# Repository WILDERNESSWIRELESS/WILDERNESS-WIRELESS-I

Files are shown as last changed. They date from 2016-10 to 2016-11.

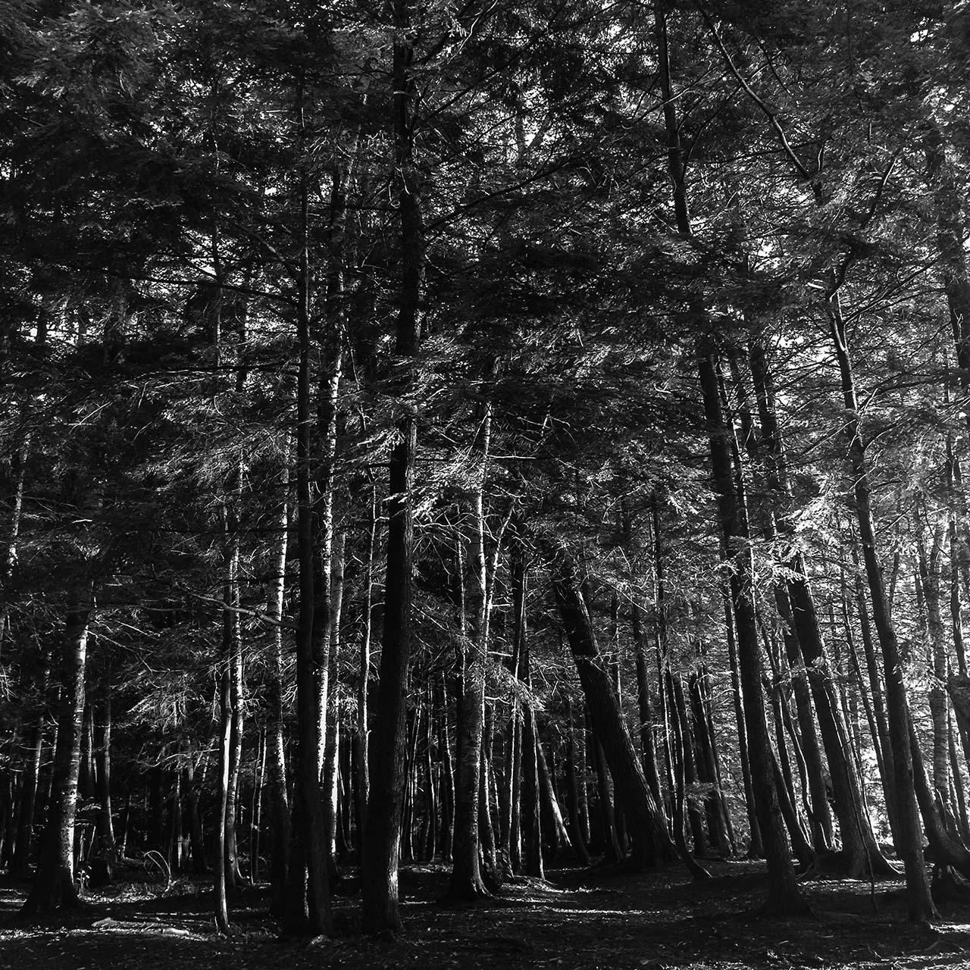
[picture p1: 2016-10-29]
docs/www.jpg

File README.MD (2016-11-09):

# Wilderness Wireless Map

## INTRODUCTION

### About

The following are instructions for making your very own Solar-Powered Wilderness Wireless WiFi Access Point and Web Server. When you are finished, there will be an access point (AP) with a name (SSID) of your own choosing. When you or someone else connects to this AP with a phone or computer, a captive portal page will open, displaying a web page of your own design, not unlike the captive portal pages of some paid public wifi networks. This personal area network (PAN) is not connected to the internet and does not provide a route to any place on the internet. This AP is in essence its own internet. After connecting, all http requests are resolved to the internal address. The information contained here has been pulled from many difference sources and integrates the work of many others without whose work this project would not be possible. Please see the references.md file for acknowedgements and links to sources.

### Materials and Tools

A comprehensive list of materials is provided as an Adafruit wishlist that can be accessed [here]() You may try to source materials from other places, but there is no guarantee the project will work as expected. This project involves soldering, so a basic set of electronics tools is required. Here's a general list of useful things:
 * Soldering iron
 * Soldering Iron Tip Cleaner
 * Solder
 * Wire Strippers
 * Wire Cutters
 * Needle Nose Pliers
 * Multimeter
 * Lighter or Heat Gun

### Disclaimer

This information is provided free and without warranty. I offer no guarantee that this project will work as stated. The author or any of the included sources are not responsible for any wrongdoing, damage, transgression of rules, laws or regulations. Use at your own risk.

### License

**CC** Creative Commons Attribution, Non-Commercial Share-Alike

## PHASE 1

### Prepare and Solder Hardware

- **Solder Capacitor on Charger**
  * You can find instructions from Adafruit [here](https://learn.adafruit.com/usb-dc-and-solar-lipoly-charger/solar-charger-preparation)

- **Solder JST connector**
  * The Adafruit charger comes with a JST connector with bare wire ends. It is difficult to  plug these tiny wires into a breadboard, so cut a jumper wire in half, solder each end to a bare wire. Use heat-shring tubing to insulate wires. Hold onto this DIY cable for now...

- **Solder Headers on the Feather**
  * The Adafruit Feather Huzzah ESP8266 comes with male header pins. You must cut the headers to the correct length and solder them to the board. You can find instructions from Adafruit [here](https://learn.adafruit.com/adafruit-feather-huzzah-esp8266/using-arduino-ide?view=all#assembly)

- **Charge Battery**
  * Plug the LiPoly battery's JST connector into the BATT port on the charger. You can charge the battery by connecting the charger to your laptop or a wall adapter/charger with a mini USB cable.

### Install Software Tools and Their Dependencies

! _WIN users might have an easier time using NodeMCU Flasher instead of setting up python, etc. It can be found [here](https://github.com/nodemcu/nodemcu-flasher)_

  - **Prepare esptool.py**
    * The Adafruit Feather already has NodeMCU firmware installed, but we need to use a custom version for our web server to work properly. The firmware is flashed to the Feather using a Python tool called esptool.py. You must first determine if you have Python installed.
      * **OSX:** Open Terminal (if you don't know where it is, search in spotlight). Type ``` python --version``` in the terminal. You should see something like ```Python 2.7.10``` returned. If not, skip down to Python installation.
      * **WIN:** Search for run or run.exe. Type CMD in the run dialog box. The command line terminal should open. Type ``` python --version``` in the terminal. You should see something like ```Python 2.7.10``` returned. If not, skip down to Python installation.
    * Install Python if you don't have it. Get it [here](https://www.python.org/downloads/)
    * esptool.py is a python program that will help you flash firmware to the Feather. You can find instructions [here](https://github.com/espressif/esptool)
  * **Install VCPdrivers for Feather:** The Feather uses a Silicon Labs CP2104 USB-Serial converter onboard with 921600 max baudrate for uploading. You must install drivers for this chip before connecting it to your computer and flashing the firmware. Download and install the Virtual Com Port drivers for you operating system [here](https://www.silabs.com/products/mcu/Pages/USBtoUARTBridgeVCPDrivers.aspx)
  * **Connect Feather to your computer with a micro USB cable.**
  * **Locate firmware.** The firmware for the Feather is located in the _firmware_ folder in this repository. It is easiest to navigate to that folder using your command line terminal. The firmware file is: ```NodeMCU-FW-CaptiveIntraweb.bin```
  * **Flash Firmware:** With Python, esptool.py and VCP drivers now installed, flash the firmware using this command in your terminal:
  ```
  esptool.py --port /dev/tty.SLAB_USBtoUART
    write_flash -fm dio
    -fs 32m 0x00000
    NodeMCU-FW-CaptiveIntraweb.bin
  ```
  The device you are flashing is usually ```/dev/tty.SLAB_USBtoUART``` on OSX or something like ```COM3``` on Windows. Replace ```/dev/tty.SLAB_USBtoUART``` with the correct port if different.

  ## PHASE 2

  ### Communicating With Feather

  Communication with the Feather NodeMCU firmware can be done via a Serial Terminal Application like CoolTerm (WIN/OSX) or Screen (OSX/NIX). A useful application is ESPLorer which provides a FTP-like interface for manipulating files on the Feather. Since we are going to use the Feather as a Web Server, this seems like the best tool for the job. ESPlorer application is a cross-platform Java application. You can get it from the Download it from the _tools_ folder in this repository or alternatively download it [here](http://esp8266.ru/esplorer/). Since ESPLorer is a java application, you need to have a recent version of the Java Runtime Environment (JRE) installed on your machine to use it. Try to open the _**ESPLorer.jar**_ file. If it doesn't open, you probably don't have java installed. The JRE is free and can be downloaded [here](http://www.oracle.com/technetwork/java/javase/downloads/jre8-downloads-2133155.html).

  ### Edit Server Files

  This is your own access point and webserver. You have control over the name of the accesspoint and the content of the web page. In keeping with the idea of wilderness wireless, think about what you might name your AP. Does a wilderness wireless network use a particular language? Does it have to be intelligible? Think about stumbling across a wireless network in the wilderness where there are no others around. What kind of content might you find in this network? Is it text, an image, perhaps just a color? 

  ### Upload Server Files

  ## PHASE 3

  ### Breadboard circuit

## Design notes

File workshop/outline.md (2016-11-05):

hack tutorial
orientation: the spirit of the project
https://en.wikipedia.org/wiki/Mycorrhiza
beacons
Throwies
http://www.graffitiresearchlab.com/blog/projects/led-throwies/

aram bartholl dead drops
https://deaddrops.com/

Wilderness-unplugging

software Tools
  vcp drivers
  esptool
  firmware
  esplorer

soldering
  headers
  cap
  jst/

circuit
    fritzing

flash modified node mcu firmware

play with node mcu/

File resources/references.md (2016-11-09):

# References

## Rad Networks WiFi

~~SSID: RadNetz~~

~~PWD: R@@0n3wrks~~

## github

#### The Wilderness Wireless Repository is here:

https://giantmolecules.github.io/WILDERNESS-WIRELESS/

## Arduino/ATTINY85 Battery Watchdog

#### Wake an Arduino from sleep with a watchdog timer

http://donalmorrissey.blogspot.com/2010/04/sleeping-arduino-part-5-wake-up-via.html

http://arduino.stackexchange.com/questions/19501/watchdog-approach

#### ATTINY Pinouts

http://orig06.deviantart.net/82c9/f/2013/038/3/7/attiny_web_by_pighixxx-d5u4aur.png

#### Adafruit Feather HUZZAH ESP8266

https://learn.adafruit.com/adafruit-feather-huzzah-esp8266

#### Adafruit USB, DC & Solar Lipoly Charger

https://learn.adafruit.com/usb-dc-and-solar-lipoly-charger/using-the-charger

#### Atmel sleep reference

http://www.atmel.com/webdoc/AVRLibcReferenceManual/group__avr__sleep.html

#### Measuring battery voltage with arduino

http://provideyourown.com/2012/secret-arduino-voltmeter-measure-battery-voltage/

http://digistump.com/wiki/digispark/quickref

#### Tiny AVR Programmer

https://github.com/sparkfun/Tiny-AVR-Programmer/tree/V_1.3

https://www.sparkfun.com/products/11801

## Adafruit Feather HUZZAH ESP8266

#### NodeMCU Documentation

https://nodemcu.readthedocs.io/en/master/

## ESPlorer

#### ESPlorer Homepage

http://esp8266.ru/esplorer/

#### Java Runtime Environment

http://www.oracle.com/technetwork/java/javase/downloads/jre8-downloads-2133155.html

## General

#### UTF-8 Charset

http://www.w3schools.com/charsets/ref_html_utf8.asp

## Inspiration

#### LED Throwies

http://www.graffitiresearchlab.com/blog/projects/led-throwies/

#### ESP8266 WiFi Throwies

http://hackaday.com/2015/05/03/esp8266-wifi-throwies/

## Wilderness Networks

#### Forestry Communication Tools

http://www.fao.org/forestry/communication-toolkit/en/

#### Internet of Fungus

http://www.bbc.com/earth/story/20141111-plants-have-a-hidden-internet

## Wood Wide web

http://www.newyorker.com/tech/elements/the-secrets-of-the-wood-wide-web

https://en.wikipedia.org/wiki/Mycorrhizal_network

https://rayalaseema360.wordpress.com/2016/01/31/trees-have-their-own-internet-wood-wide-web/

## LED Throwies

http://www.graffitiresearchlab.com/blog/projects/led-throwies/

## Aram Bartholl dead drops

https://deaddrops.com/

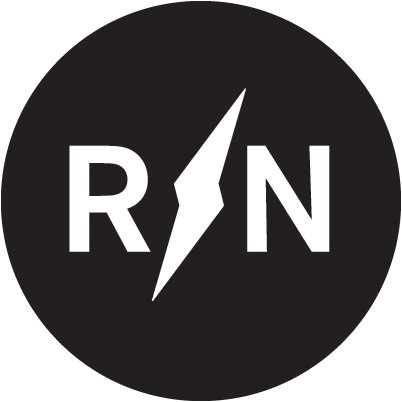
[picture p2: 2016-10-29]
media/E5fjbFVR.jpg

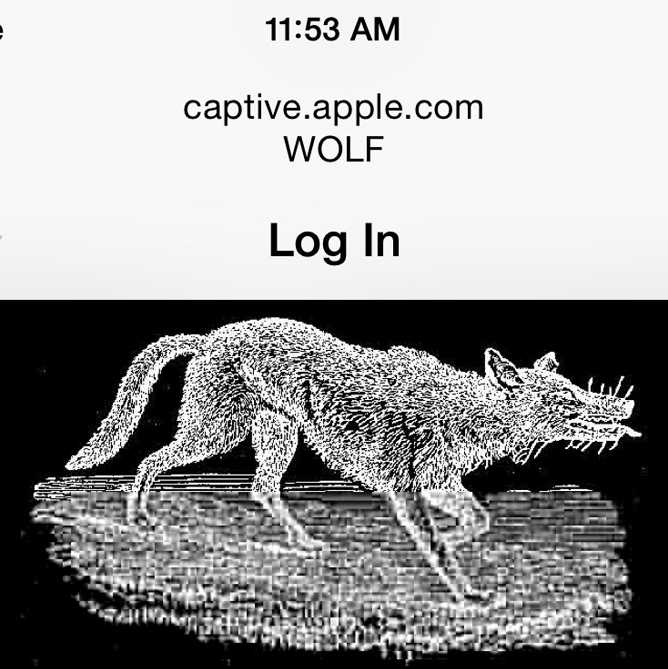
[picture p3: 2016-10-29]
media/wolf_225px.png

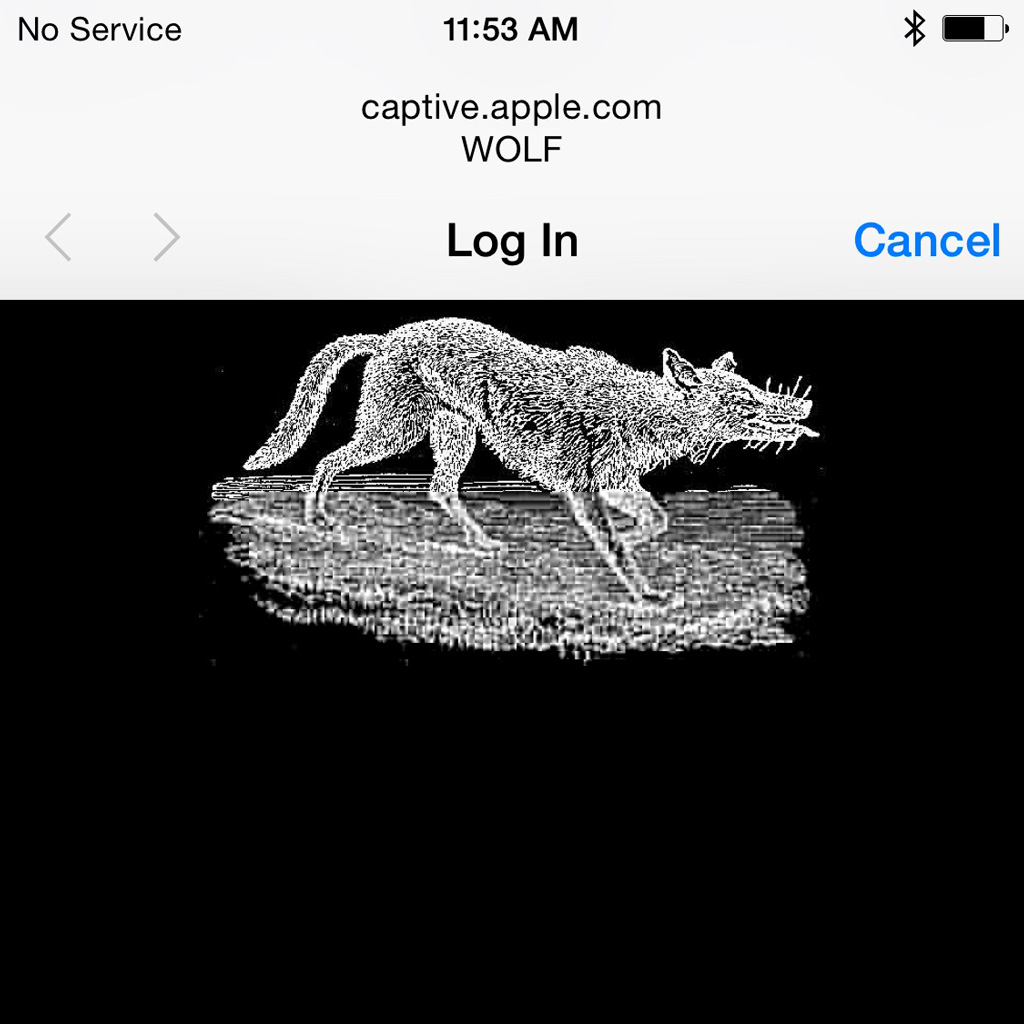
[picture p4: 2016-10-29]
media/wolf.png

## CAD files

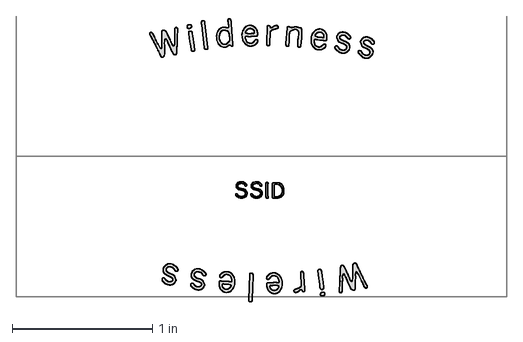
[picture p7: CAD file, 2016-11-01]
media/www-card [Converted].dxf
3.50 x 2.04 in

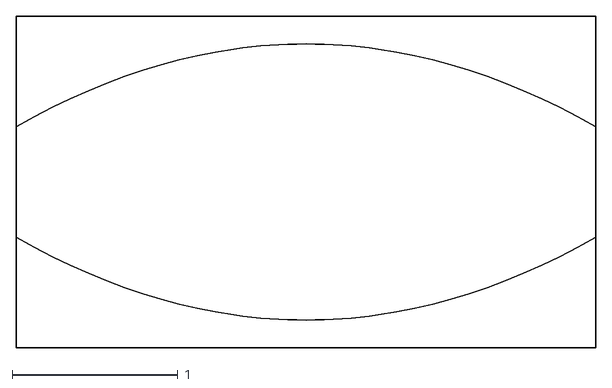
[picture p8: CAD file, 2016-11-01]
media/www-card.dxf
3.50 x 2.00

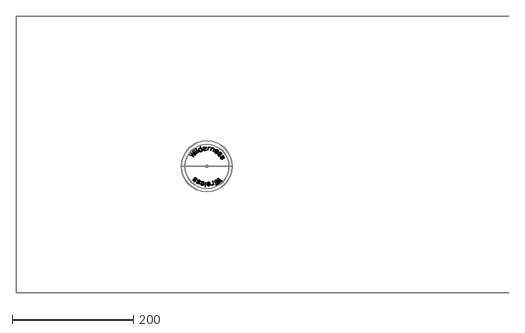
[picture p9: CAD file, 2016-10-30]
media/mason-jar-lid.dxf
813.0 x 457.0

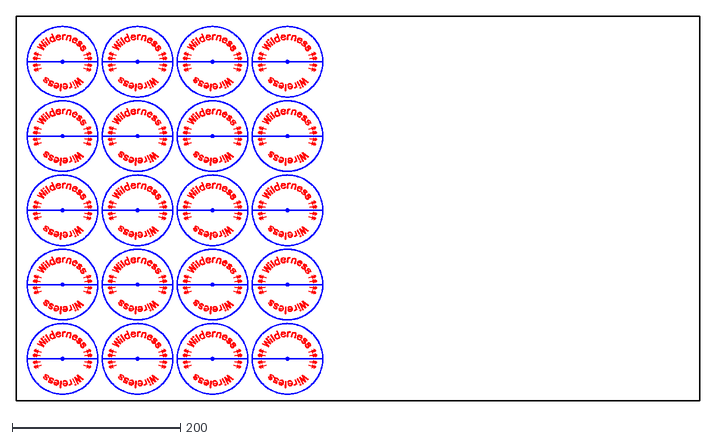
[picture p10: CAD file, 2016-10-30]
media/lids.dxf
813.0 x 457.0

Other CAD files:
media/mason-jar-lid.3dm
media/www-card.3dm

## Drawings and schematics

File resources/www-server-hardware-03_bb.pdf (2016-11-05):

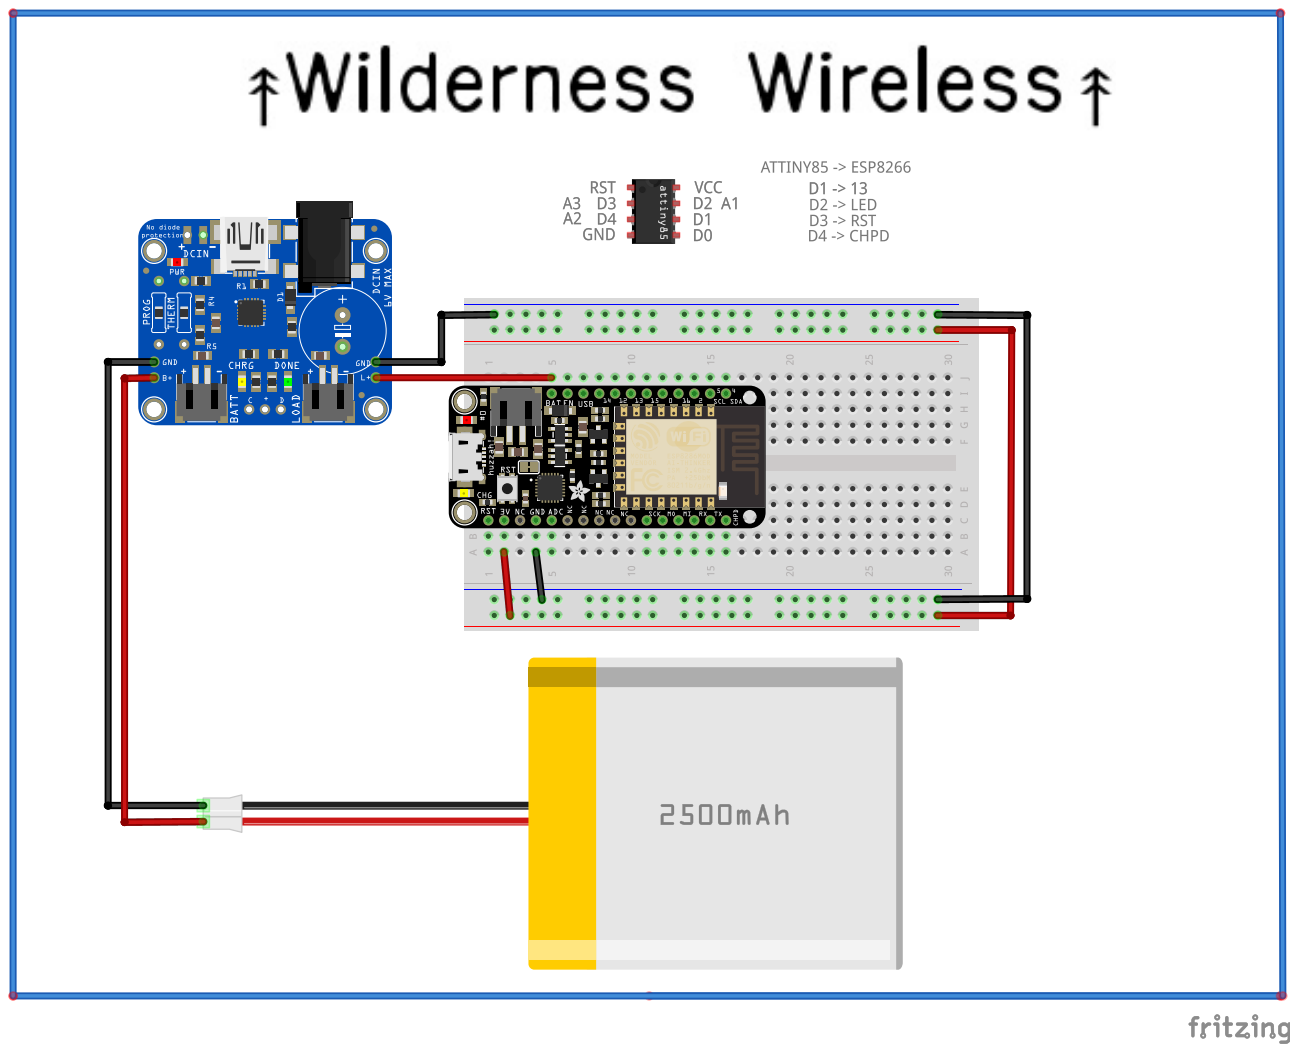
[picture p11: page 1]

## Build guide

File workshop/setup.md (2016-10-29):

# Wilderness Wireless Setup

## :floppy_disk: Install VCP (Virtual COM Port) Drivers for CP210x

* Download from [Silicon Labs](https://www.silabs.com/products/mcu/Pages/USBtoUARTBridgeVCPDrivers.aspx).

## :floppy_disk: Install ESPtool

Windows users mush have Python installed, get it [here](https://www.python.org/downloads/windows/).

OSX users already have Python installed

Follow instructions to install esptool.py [here](https://github.com/themadinventor/esptool)

WIN users might have an easier time using NodeMCU Flasher instead of setting up python, etc. It con be found [here](https://github.com/nodemcu/nodemcu-flasher)

## :floppy_disk: Grab Firmware

NodeMCU Firmware releases can be found [here](https://github.com/nodemcu/nodemcu-firmware/releases).

The default Adafruit NodeMCU firmware is __0.9.5 build 20150318__

The firmware for the Captive Intraweb is in the CaptiveIntraweb repository listed below.

OSX Terminal Command to flash ESP8266 with firmware. ```NodeMCU-FW-CaptiveIntraweb.bin``` should be replaced with the proper firmware filename.
```
esptool.py --port /dev/tty.SLAB_USBtoUART
  write_flash -fm dio
  -fs 32m 0x00000
  NodeMCU-FW-CaptiveIntraweb.bin
```

## Grab ESPlorer

Download it from [here](http://esp8266.ru/esplorer/).

ESPlorer is a cross-platform tool for working with the ESP8266. It is written in Java, so if it doesn't run on either OSX or WIN, grab the latest JRE (Java Runtime Environment) from [Oracle](http://www.oracle.com/technetwork/java/javase/downloads/jre8-downloads-2133155.html).

## :book: Read the NodeMCU Documentation
Take a look [here](https://nodemcu.readthedocs.io/en/master/).

## :electric_plug: Adafruit's Introduction to the Hardware

Take a look [here](https://learn.adafruit.com/adafruit-feather-huzzah-esp8266).

## Grab the CaptiveIntraweb code from github

Find it [here](https://github.com/reischle/CaptiveIntraweb)

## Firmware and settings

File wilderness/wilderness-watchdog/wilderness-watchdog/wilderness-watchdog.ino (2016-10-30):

/*
 * TO DO
 * 
 * -Need some way of telling if the ESP8266 is alive or dead
 * 
 */

#include <avr/sleep.h>    // Sleep Modes
#include <avr/power.h>    // Power management
#include <avr/wdt.h>      // Watchdog timer

#define SUP_PIN  1
#define LED_PIN  2
#define RST_PIN  3
#define WAKE_PIN 4
#define THRESH   3200

//#define ADC_PIN  1
//#define LED_PIN  4

int f_wdt = 0;
long batteryVoltage = 0;
int serverUp = 0;

void setup() {
  pinMode(SUP_PIN, INPUT);
  pinMode(LED_PIN, OUTPUT);
  digitalWrite(LED_PIN, LOW);
  pinMode(WAKE_PIN, OUTPUT);
  digitalWrite(WAKE_PIN, HIGH);
  pinMode(RST_PIN, OUTPUT);
  digitalWrite(RST_PIN, HIGH);
  enterSleep();
}

void loop() {
  wdt_reset();
  batteryVoltage = readVcc();
  serverUp = digitalRead(SUP_PIN);
  
  if (batteryVoltage < THRESH ) {
    // Turn OFF FET
    digitalWrite(WAKE_PIN, LOW);
  }

/* Something wrong here. Keeps resetting */
/* Solved... had to actually wire it to pin 13 on esp :/ */
/*another problem, though: fet switch won't work at battery voltage*/
/*
/*
 * ok
 * i can't use the FET switch
 * not enough headroom
 * unless i find a better suited fet
 * take chpd low when vbat is too low
 * take chpd high when vbat is good
 * temorarily ground rst afterwards
 */

 if(batteryVoltage > THRESH){
  // TURN ESP8266 ON
  digitalWrite(WAKE_PIN, HIGH);
 }
  
  if(batteryVoltage >= THRESH && serverUp < 1) {
    // Reset ESP8266
    digitalWrite(RST_PIN, LOW);
    delay(250);
    digitalWrite(RST_PIN, HIGH);
  }
  enterSleep();
}

void enterSleep(void) {
  noInterrupts ();       // timed sequence coming up
  // pat the dog
  wdt_reset();
  // clear various "reset" flags
  MCUSR = 0;
  // allow changes, disable reset, clear existing interrupt
  WDTCR = bit (WDCE) | bit (WDE) | bit (WDIF);
  // set interrupt mode and an interval (WDE must be changed from 1 to 0 here)
  WDTCR = bit (WDIE) | bit (WDP3) | bit (WDP0);    // set WDIE, and 8 seconds delay
  set_sleep_mode(SLEEP_MODE_PWR_DOWN);
  sleep_enable ();       // ready to sleep
  interrupts ();         // interrupts are required now
  sleep_mode ();          // sleep
  sleep_disable ();      // precaution
}

ISR(WDT_vect) {
  heartbeat();
}

void heartbeat() {
  
  // We're alive!
  digitalWrite(LED_PIN, HIGH);
  delay(500);
  digitalWrite(LED_PIN, LOW);
  delay(500);
  
  // Message Voltage > THRESH
  
  if(batteryVoltage > THRESH){
    for(int i = 0; i < 4; i++){
      digitalWrite(LED_PIN, HIGH);
      delay(100);
      digitalWrite(LED_PIN, LOW);
      delay(100);
    }
  }
  
  // Message Voltage < THRESH
  
  if(batteryVoltage < THRESH){
    for(int i = 0; i < 2; i++){
      digitalWrite(LED_PIN, HIGH);
      delay(200);
      digitalWrite(LED_PIN, LOW);
      delay(200);
    }
  }
  
}

long readVcc() {
  // Read 1.1V reference against AVcc
  // set the reference to Vcc and the measurement to the internal 1.1V reference
#if defined(__AVR_ATmega32U4__) || defined(__AVR_ATmega1280__) || defined(__AVR_ATmega2560__)
  ADMUX = _BV(REFS0) | _BV(MUX4) | _BV(MUX3) | _BV(MUX2) | _BV(MUX1);
#elif defined (__AVR_ATtiny24__) || defined(__AVR_ATtiny44__) || defined(__AVR_ATtiny84__)
  ADMUX = _BV(MUX5) | _BV(MUX0);
#elif defined (__AVR_ATtiny25__) || defined(__AVR_ATtiny45__) || defined(__AVR_ATtiny85__)
  ADMUX = _BV(MUX3) | _BV(MUX2);
#else
  ADMUX = _BV(REFS0) | _BV(MUX3) | _BV(MUX2) | _BV(MUX1);
#endif

  delay(2); // Wait for Vref to settle
  ADCSRA |= _BV(ADSC); // Start conversion
  while (bit_is_set(ADCSRA, ADSC)); // measuring

  uint8_t low  = ADCL; // must read ADCL first - it then locks ADCH
  uint8_t high = ADCH; // unlocks both

  long result = (high << 8) | low;

  result = 1125300L / result; // Calculate Vcc (in mV); 1125300 = 1.1*1023*1000
  return result; // Vcc in millivolts
}

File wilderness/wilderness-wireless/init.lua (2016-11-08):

print ("---------------------")
print("Setting up WiFi AP...")

 wifi.setmode(wifi.SOFTAP)
 cfg={}
     --cfg.ssid="↟↟↟↟↟↟↟↟"
     cfg.ssid="wire urs"
     wifi.ap.config(cfg)

print("Done.")
print ("---------------------")

majorVer, minorVer, devVer, chipid, flashid, flashsize, flashmode, flashspeed = node.info();
print("Flash size is "..flashsize.." kBytes.")

remaining, used, total=file.fsinfo()
    print("File system:\n Total : "..(total/1024).." kBytes\n Used  : "..(used/1024).." kBytes\n Remain: "..(remaining/1024).." kBytes")

-- Brett's addition

print ("---------------------")
print("Setting UP Flag")
-- Make a GPIO pin HIGH to signal server is up
-- debug LED
gpio.mode(3, gpio.OUTPUT)
gpio.write(3, gpio.LOW) --PCB pin 0
-- turn FLAG ON
gpio.mode(7, gpio.OUTPUT)
gpio.write(7, gpio.HIGH) --PCB pin 13
print("Done.")
print ("---------------------")

-- End Brett's addition

local compileAndRemoveIfNeeded = function(f)
   if file.open(f) then
      file.close()
      print('Compiling:', f)
      node.compile(f)
      file.remove(f)
      collectgarbage()
    else
    print("No need to compile ", f )
    end
end
print ("---------------------")
print("Compiling LUA files...")

local serverFiles = {'dns-liar.lua', 'server.lua'}
for i, f in ipairs(serverFiles) do compileAndRemoveIfNeeded(f) end

compileAndRemoveIfNeeded = nil
serverFiles = nil
collectgarbage()

print("Compiling done.")
print ("---------------------")

function startup()
    uart.on("data")
    if abort == true then
        print('startup aborted')
        return
        end
	print ("---------------------")
    print('Starting HTTP Server')
    dofile('server.lc')
    print ('Starting DNS Server')
    dofile('dns-liar.lc')
	print ("---------------------")
    end

 -- prepare abort procedure
    abort = false
    print('Send some xxxx Keystrokes now to abort startup.')
    -- if <CR> is pressed, abort
      uart.on("data", "x",
      function(data)
        print("receive from uart:", data)
        if data=="x" then
          abort = true
          uart.on("data")
        end
    end, 0)


print ('Will launch servers in 5 seconds...')
tmr.alarm(0,5000,0,startup)
